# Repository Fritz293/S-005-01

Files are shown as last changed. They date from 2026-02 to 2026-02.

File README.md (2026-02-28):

# Raspberry Pi Multi-Status LED HAT

An industrial-grade Raspberry Pi HAT designed for high-visibility status monitoring using the **OSRAM DISPLIX® P3333 RGB LED** array. This board features professional-level power protection and follows the official Raspberry Pi HAT specifications.

## 🚀 Current Progress: Phase 1 (Schematic Complete)
- [x] Power Filtering & ESD Protection
- [x] High-Efficiency Reverse Polarity Protection (P-MOSFET)
- [x] Logic Level Shifting for 5V LED Driving
- [x] HAT ID EEPROM Implementation
- [ ] PCB Layout & Routing (Next Step)

---

## 🛠 Hardware Specifications

### 1. Power & Protection
To ensure the Raspberry Pi 5 remains stable during transient spikes, the 5V rail includes:
* **Reverse Polarity Protection:** Implemented via an **AO3401A P-Channel MOSFET**. This provides protection with negligible voltage drop (<0.05V) compared to a standard Schottky diode.
* **Overvoltage Protection:** Dual **5.6V 3W Zener/TVS diodes** ($D10, D11$).
* **Current Limiting:** A **375mA Fuse (F1)** protects the logic from downstream shorts.
* **Filtering:** 10µF and 100nF ceramic/tantalum capacitors for noise decoupling.

### 2. LED Driver Circuit
The board drives an **OSRAM KRTB LSLPS1.32** RGB LED via a high-side/low-side configuration:
* **Switching:** Three **BSS138 N-MOSFETs** act as logic-level shifters, allowing the Pi's 3.3V GPIOs to safely switch the 5V LED rail.
* **Current Calibration (at 20mA):**
    * **Red:** 150Ω
    * **Green:** 120Ω (Updated for Osram Vf)
    * **Blue:** 110Ω (Updated for Osram Vf)
* **ESD Safety:** **PESD5V0S1UL** protection diodes are placed at the external connector and MOSFET drains to prevent static damage.

### 3. Controller Interface
| Function | GPIO | Physical Pin |
| :--- | :--- | :--- |
| **Power/Idle** | GPIO 17 | Pin 11 |
| **Media Activity** | GPIO 27 | Pin 13 |
| **Error State** | GPIO 22 | Pin 15 |
| **ID_SDA** | EEPROM Data | Pin 27 |
| **ID_SCL** | EEPROM Clock | Pin 28 |

---

## 📝 Design Notes
> **Note on EEPROM Wiring:** The AT24C32 EEPROM is connected to the dedicated `ID_SD` and `ID_SC` pins (Pins 27/28) to allow the Raspberry Pi to automatically load the device tree overlay at boot.

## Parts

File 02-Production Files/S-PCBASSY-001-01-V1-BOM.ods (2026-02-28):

 | Component list
 |  |  |  | BOM for Variant [V1] of Project [S-PCBASSY-001-01.PrjPCB] (PCB Document : S-PCBASSY-001-01.PcbDoc)
 | Project: |  |  | S-PCBASSY-001-01-V1-BOM
 | Variant: |  |  | V1
 | Report Date:
 | Print Date: |  |  |  |  |  |  |  |  |  |  | Alternative Supplier |  | Equivalent Part #
# | LibRef | Manufacturer | Part # | Supplier | Supplier Part # | Description | Footprint1 | Designator | Value | Temp Range | Production Supplier | Supplier 2 | Supplier 2 Part # | Equivalent Part # | Equivalent Manufacturer | Equivalent Supplier | Equivalent Supplier Part # | Quantity | DNP
1 | 100n |  |  |  |  |  | Capacitor_SMD:C_0603_1608Metric | C1 |  |  |  |  |  |  |  |  |  | 1 |  | ~
2 | KEMET T491A106K016AT | KEMET | T491A106K016AT | Mouser | 80-T491A106K016 | Tantalum Capacitors - Solid SMD 16V 10uF 1206 10% ESR=3Ohms | Capacitor_Tantalum_SMD:CP_EIA-3216-18_Kemet-A | C2 | 10uF |  |  |  |  |  |  |  |  | 1 |  | https://octopart.com/part/kemet/T491A106K016AT
3 | Samsung CL21B104KBCNNNC | Samsung Electro-Mechanics | CL21B104KBCNNNC | DigiKey | 1276-1003-1-ND | CAP CER 0.1UF 50V X7R 0805 | Capacitor_SMD:C_0805_2012Metric | C3 | 0.1uF |  |  |  |  |  |  |  |  | 1 |  | https://octopart.com/search?q=Samsung+CL21B104KBCNNNC&currency=USD&specs=0
4 | PESD5V0L1ULD | Nexperia | PESD5V0L1ULD,315 | Mouser | 771-PESD5V0L1ULD315 | ESD Protection Diodes / TVS Diodes PESD5V0L1ULD/SOD882D/XSON2 | Diode_SMD:D_SOD-882D | D1,D3, D2 |  |  |  |  |  |  |  |  |  | 2 | DNP | "https://assets.nexperia.com/documents/data-sheet/PESD5V0L1ULD.pdf
6 | PESD5V0S1UL | Nexperia | PESD5V0L1ULD,315 | Mouser | 771-PESD5V0L1ULD315 | ESD Protection Diodes / TVS Diodes PESD5V0L1ULD/SOD882D/XSON2 | Diode_SMD:D_SOD-882 | D4,D5,D6,D7,D8,D9 |  |  |  |  |  |  |  |  |  | 8 |  | https://assets.nexperia.com/documents/data-sheet/PESD5V0S1UL.pdf
7 | 5V6, 3W | Vishay | BZG05C5V6-E3-TR | RS | 699-7758 | Zener Diodes 1.25W, BZG05C Series, Vishay Semiconductor | Diode_SMD:D_SMA | D10,D11 |  |  |  |  |  |  |  |  |  | 2 |  | https://za.rs-online.com/web/p/zener-diodes/6997758
8 | LED | OSRAM | LG R971 | EBV Elektronik | LG R971 | Green 570nm LED Indication - Discrete 2.2V 0805 (2012 Metric) | LED_SMD:LED_0603_1608Metric | D12 |  |  |  |  |  |  |  |  |  | 1 |  | ~
9 | SS14 | Vishay | SS14-E3/61T | Mouser |  | Schottky Rectifier 40V 1A SMA (Do Not Populate | Diode_SMD:D_SMA | D13 |  |  |  |  |  |  |  |  |  | 1 | DNP | https://www.vishay.com/docs/88746/ss12.pdf
10 | 375mA | Littelfuse | 0467.375NR | Mouse r |  | Fuse 375mA 32V 0603 Fast Acting | Fuse:Fuse_0603_1608Metric | F1 |  |  |  |  |  |  |  |  |  | 1 |  | https://www.littelfuse.com/media?itemid=cefcd49a-0e08-48b9-a5f1-60cfdadaed6d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
11 | GPIO |  |  |  |  |  | Connector_PinSocket_2.54mm:PinSocket_2x20_P2.54mm_Vertical | J1 |  |  |  |  |  |  |  |  |  | 1 |  | ~
12 | 43650-0428 | Molex | 436500428 | Mouser |  | Connector Header Micro-Fit 3.0 4 Pos | Connector:43650-04YY_272829 | J2 |  |  |  |  |  |  |  |  |  | 1 |  | https://www.molex.com/pdm_docs/sd/436500227_sd.pdf
13 | ID_WP |  |  |  |  |  | Connector_PinHeader_2.54mm:PinHeader_1x02_P2.54mm_Vertical_SMD_Pin1Left | JP1 |  |  |  |  |  |  |  |  |  | 1 |  | ~
14 | BSS138 | ONsemi | BSS138 | Mouser |  | N-Channel MOSFET 50V 360mA SOT-23 | Package_TO_SOT_SMD:SOT-23 | Q1,Q2,Q3 |  |  |  |  |  |  |  |  |  | 3 |  | https://www.onsemi.com/pub/Collateral/BSS138-D.PDF
15 | AO3401A | Alpha & Omega | AO3401A | Mouser |  | P-Channel MOSFET 30V 4A SOT-23 | Package_TO_SOT_SMD:SOT-23 | Q4 |  |  |  |  |  |  |  |  |  | 1 |  | http://www.aosmd.com/pdfs/datasheet/AO3401A.pdf
16 | 3.9k | Yageo | RC0603FR-073K9L |  |  | Thick Film Resistor, 1%, 0.1W (I2C Pull-ups) | Capacitor_SMD:C_0603_1608Metric | R1,R2 |  |  |  |  |  |  |  |  |  | 2 |  | ~
17 | 2k2 | Panasonic | ERJ-3EKF2201V |  |  | Thick Film Resistor, 1%, 0.1W (5V Power Indicator) | Resistor_SMD:R_0603_1608Metric_Pad0.98x0.95mm_HandSolder | R3 |  |  |  |  |  |  |  |  |  | 1 |  | ~
18 | 100k | Yageo | RC0603FR-07100KL |  |  | Thick Film Resistor, 1%, 0.1W (P-FET Gate Pull-down) | Resistor_SMD:R_0603_1608Metric_Pad0.98x0.95mm_HandSolder | R4 |  |  |  |  |  |  |  |  |  | 1 |  | ~
19 | 100 | Vishay | CRCW0603100RFKEA |  |  | Thick Film Resistor, 1%, 0.1W (Gate Damping) | Capacitor_SMD:C_0603_1608Metric,Resistor_SMD:R_0603_1608Metric_Pad0.98x0.95mm_HandSolder | Rg1,Rg2,Rg3,Rg6 |  |  |  |  |  |  |  |  |  | 4 |  | ~
20 | 150 | Panasonic | ERJ-3EKF1500V |  |  | Thick Film Resistor, 1%, 0.1W (Red/Error LED Limiter) | Capacitor_SMD:C_0603_1608Metric | Rg4,Rg5 |  |  |  |  |  |  |  |  |  | 2 |  | ~
21 | 10k | Yageo | RC0603FR-0710KL |  |  | Thick Film Resistor, 1%, 0.1W (Logic Pull-downs) | Capacitor_SMD:C_0603_1608Metric | Rpd1,Rpd2,Rpd3 |  |  |  |  |  |  |  |  |  | 3 |  | ~
22 | CAT24C256 | ONsemi | CAT24C256WI-GT3 | Mouser |  | EEPROM 256kb I2C 1MHz SOIC-8 | Package_SO:SOIC-8_3.9x4.9mm_P1.27mm | U1 |  |  |  |  |  |  |  |  |  | 1 |  | https://www.onsemi.cn/PowerSolutions/document/CAT24C256-D.PDF

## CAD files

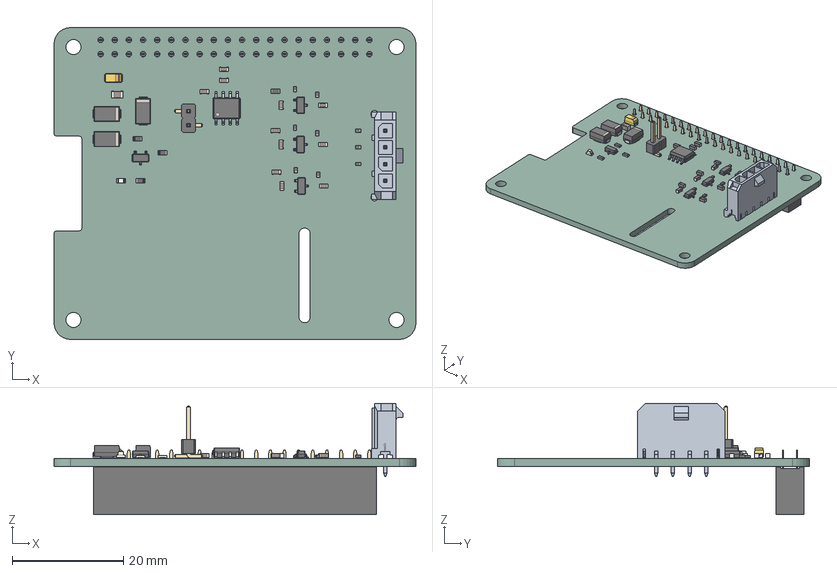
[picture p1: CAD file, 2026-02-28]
05-Production Documentation/06-Mechanical/S-PCBASSY-001-01.step
65.0 x 56.0 x 20.0 mm
C_0603_1608Metric x 11
D_SMA x 3
SOT-23 x 4
R_0603_1608Metric x 3
D_SOD-882D x 2
D_SOD-882 x 7
LED_0603_1608Metric
Fuse_0603_1608Metric
PinHeader_1x02_P2.54mm_Vertical_SMD_Pin1Left
C_0805_2012Metric
SOIC-8_3.9x4.9mm_P1.27mm
CP_EIA-3216-18_Kemet-A
PinSocket_2x20_P2.54mm_Vertical
S-PCBASSY-001-01_PCB

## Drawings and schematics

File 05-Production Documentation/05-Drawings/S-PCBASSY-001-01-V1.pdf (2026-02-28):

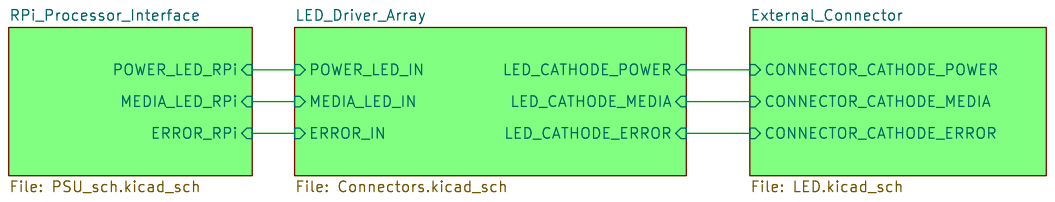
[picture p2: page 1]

Id: 1/4 Title: File: S-PCBASSY-001-01.kicad_sch Sheet: /

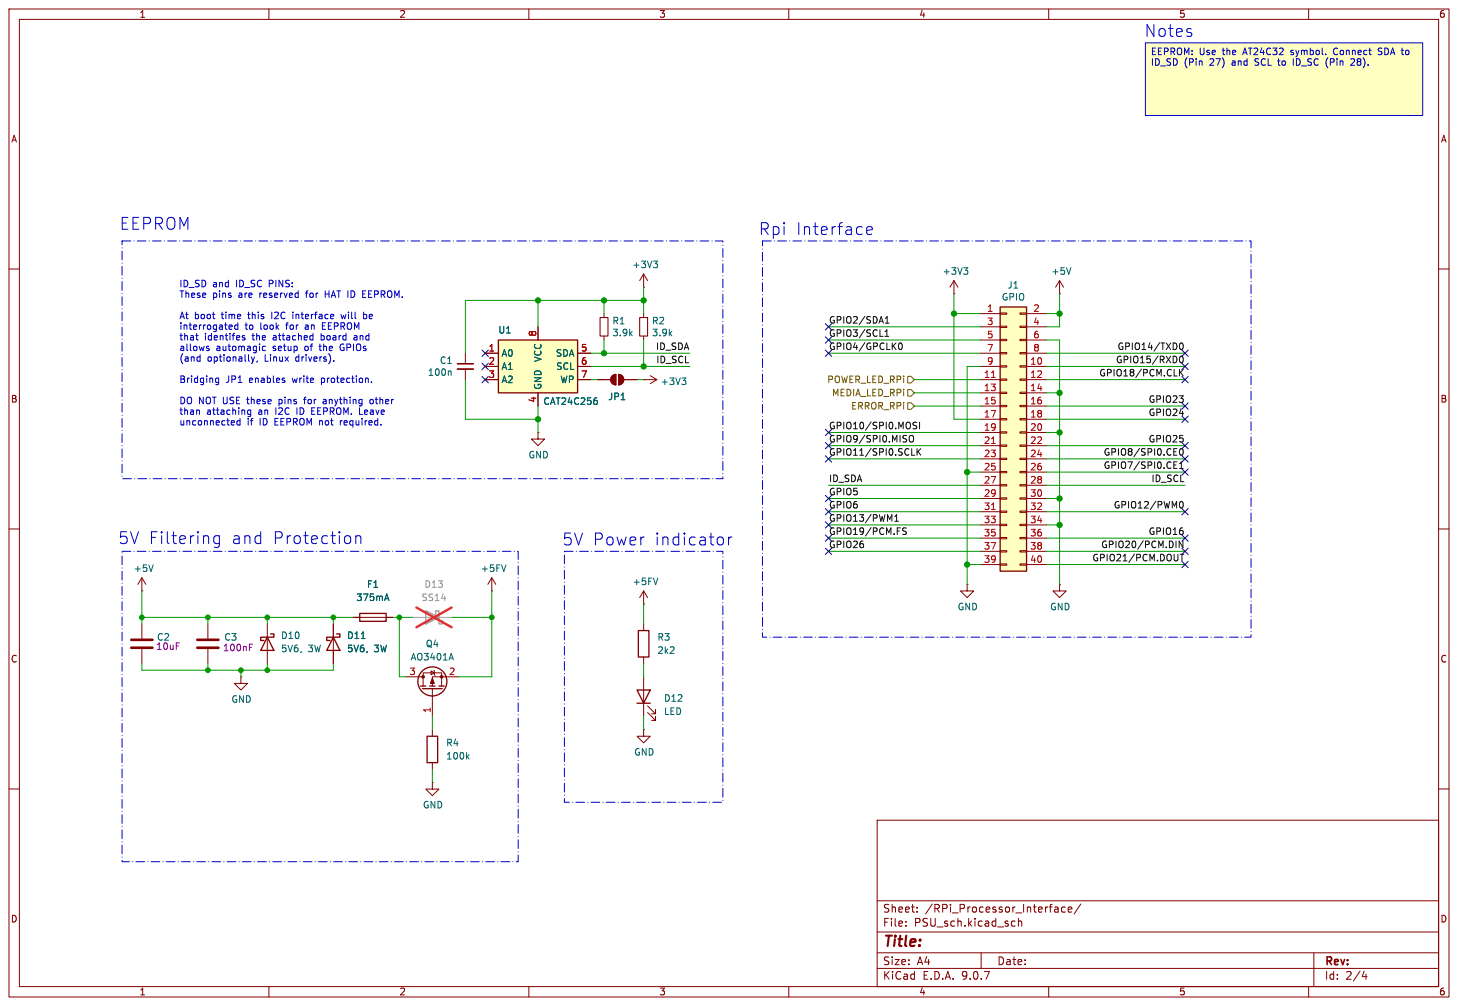
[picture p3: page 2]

ID_SD (Pin 27) and SCL to ID_SC (Pin 28).

Id: 2/4 Title: File: PSU_sch.kicad_sch Sheet: /RPi_Processor_Interface/

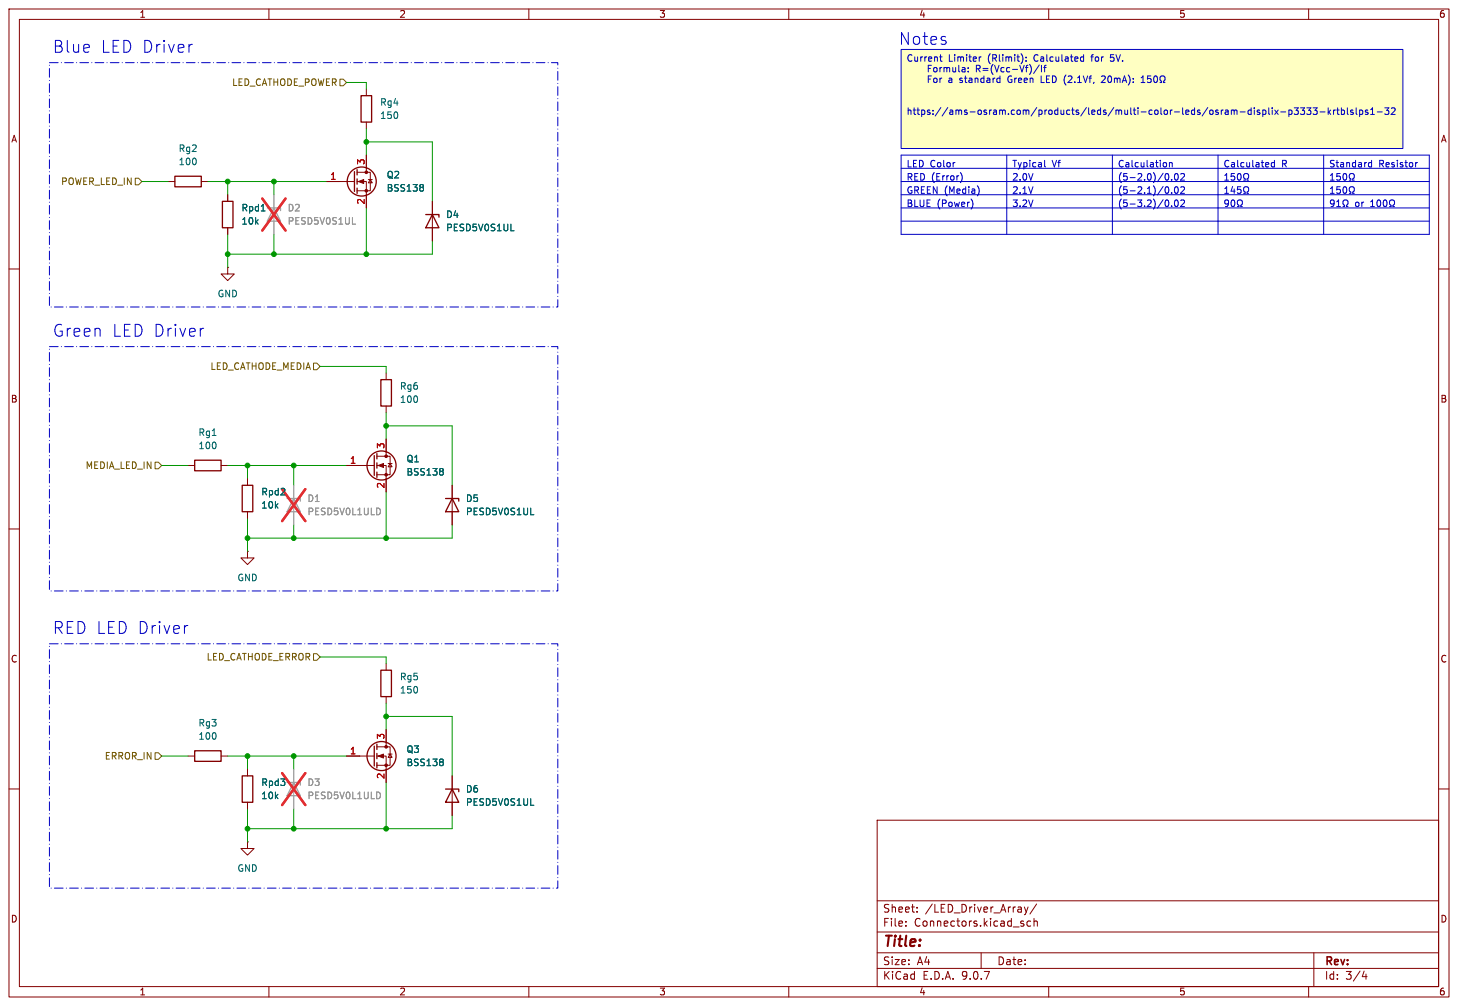
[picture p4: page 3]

https://ams-osram.com/products/leds/multi-color-leds/osram-displix-p3333-krtblslps1-32

LED Color | Typical þÿVf  2.0V 2.1V | Calculation þÿ(5"2.0)/0.02 þÿ(5"2.1)/0.02 | Calculated þÿ150© þÿ145© R | Standard Resistor RED (Error) þÿ150© GREEN (Media) þÿ150©

BLUE (Power) | 3.2V | þÿ(5"3.2)/0.02 | þÿ90© | þÿ91©or þÿ100©

Id: 3/4 Title: File: Connectors.kicad_sch Sheet: /LED_Driver_Array/

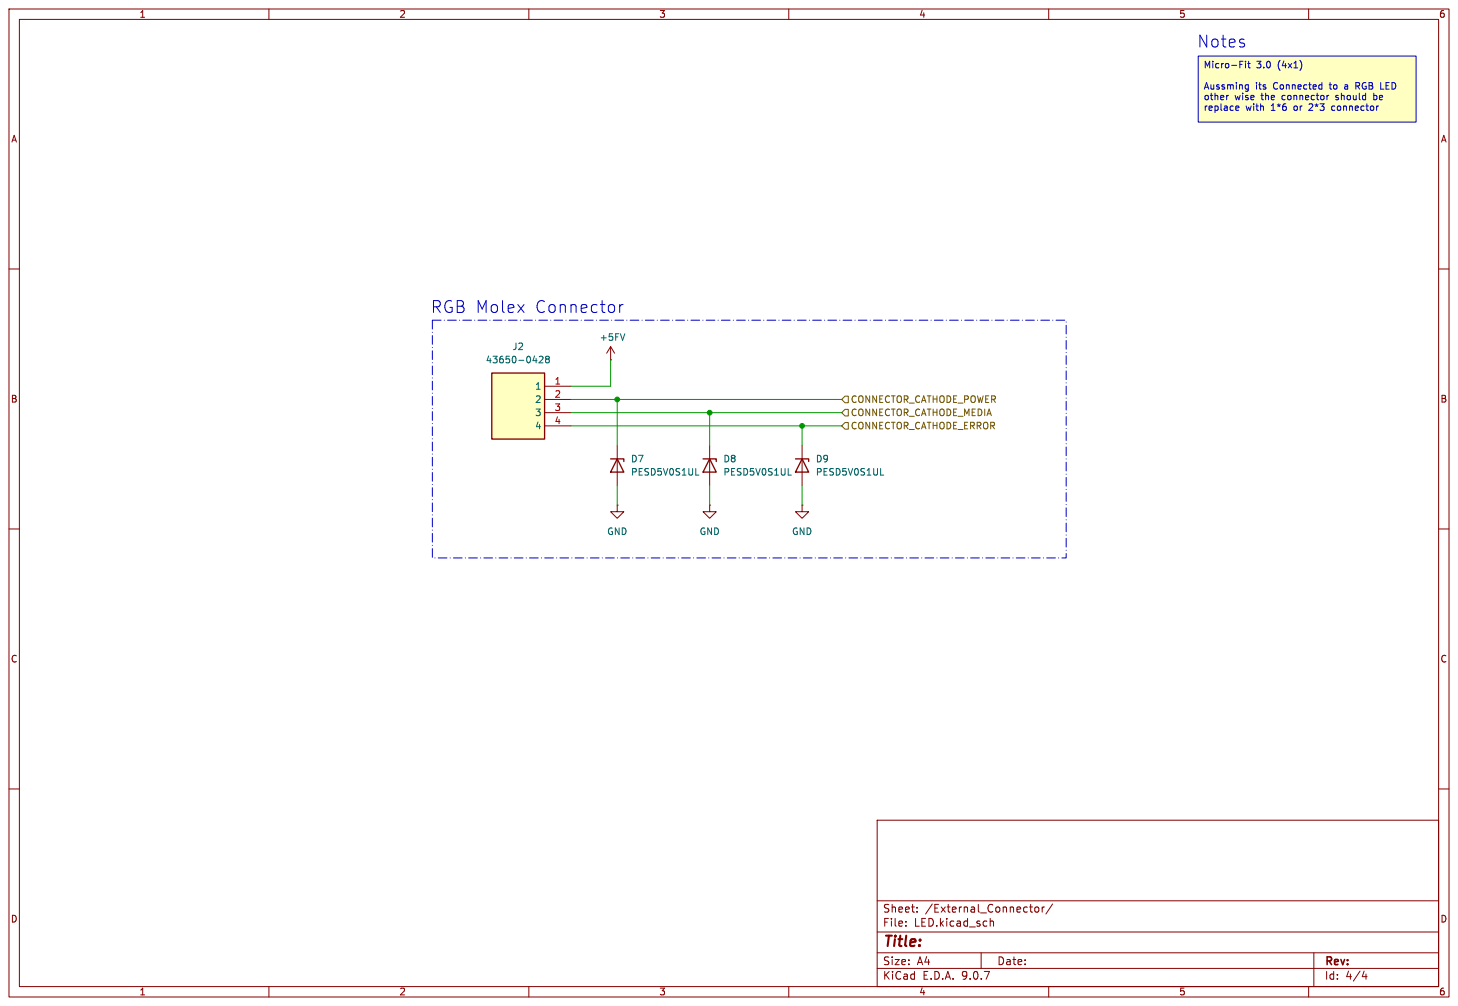
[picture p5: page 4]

Aussming its Connected to a RGB LED

replace with 1*6 or 2*3 connector RGB Molex Connector

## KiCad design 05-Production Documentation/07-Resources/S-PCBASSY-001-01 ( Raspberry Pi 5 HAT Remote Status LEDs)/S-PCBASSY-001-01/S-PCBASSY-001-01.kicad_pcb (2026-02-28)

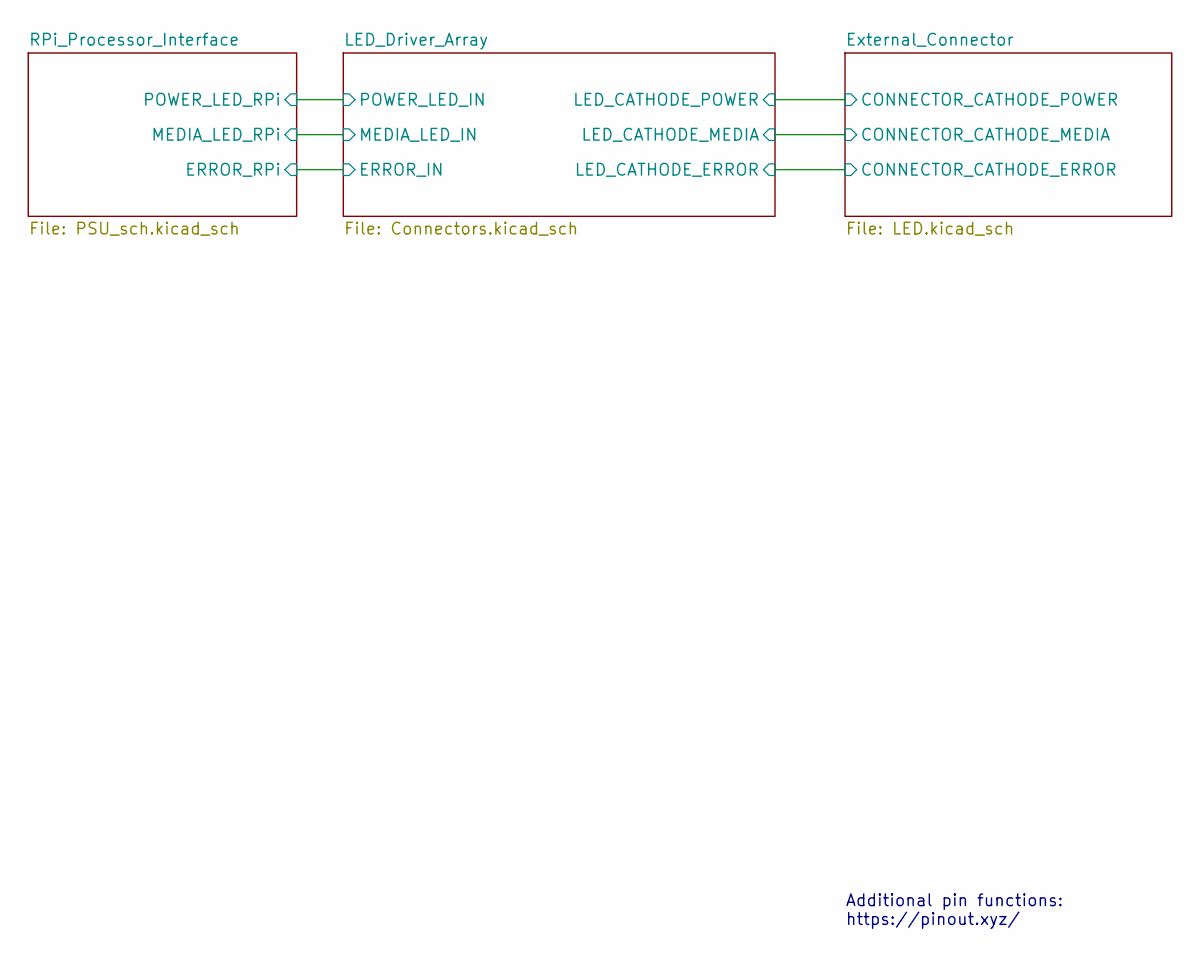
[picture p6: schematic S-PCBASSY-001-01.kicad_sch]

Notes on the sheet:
Additional pin functions: https://pinout.xyz/

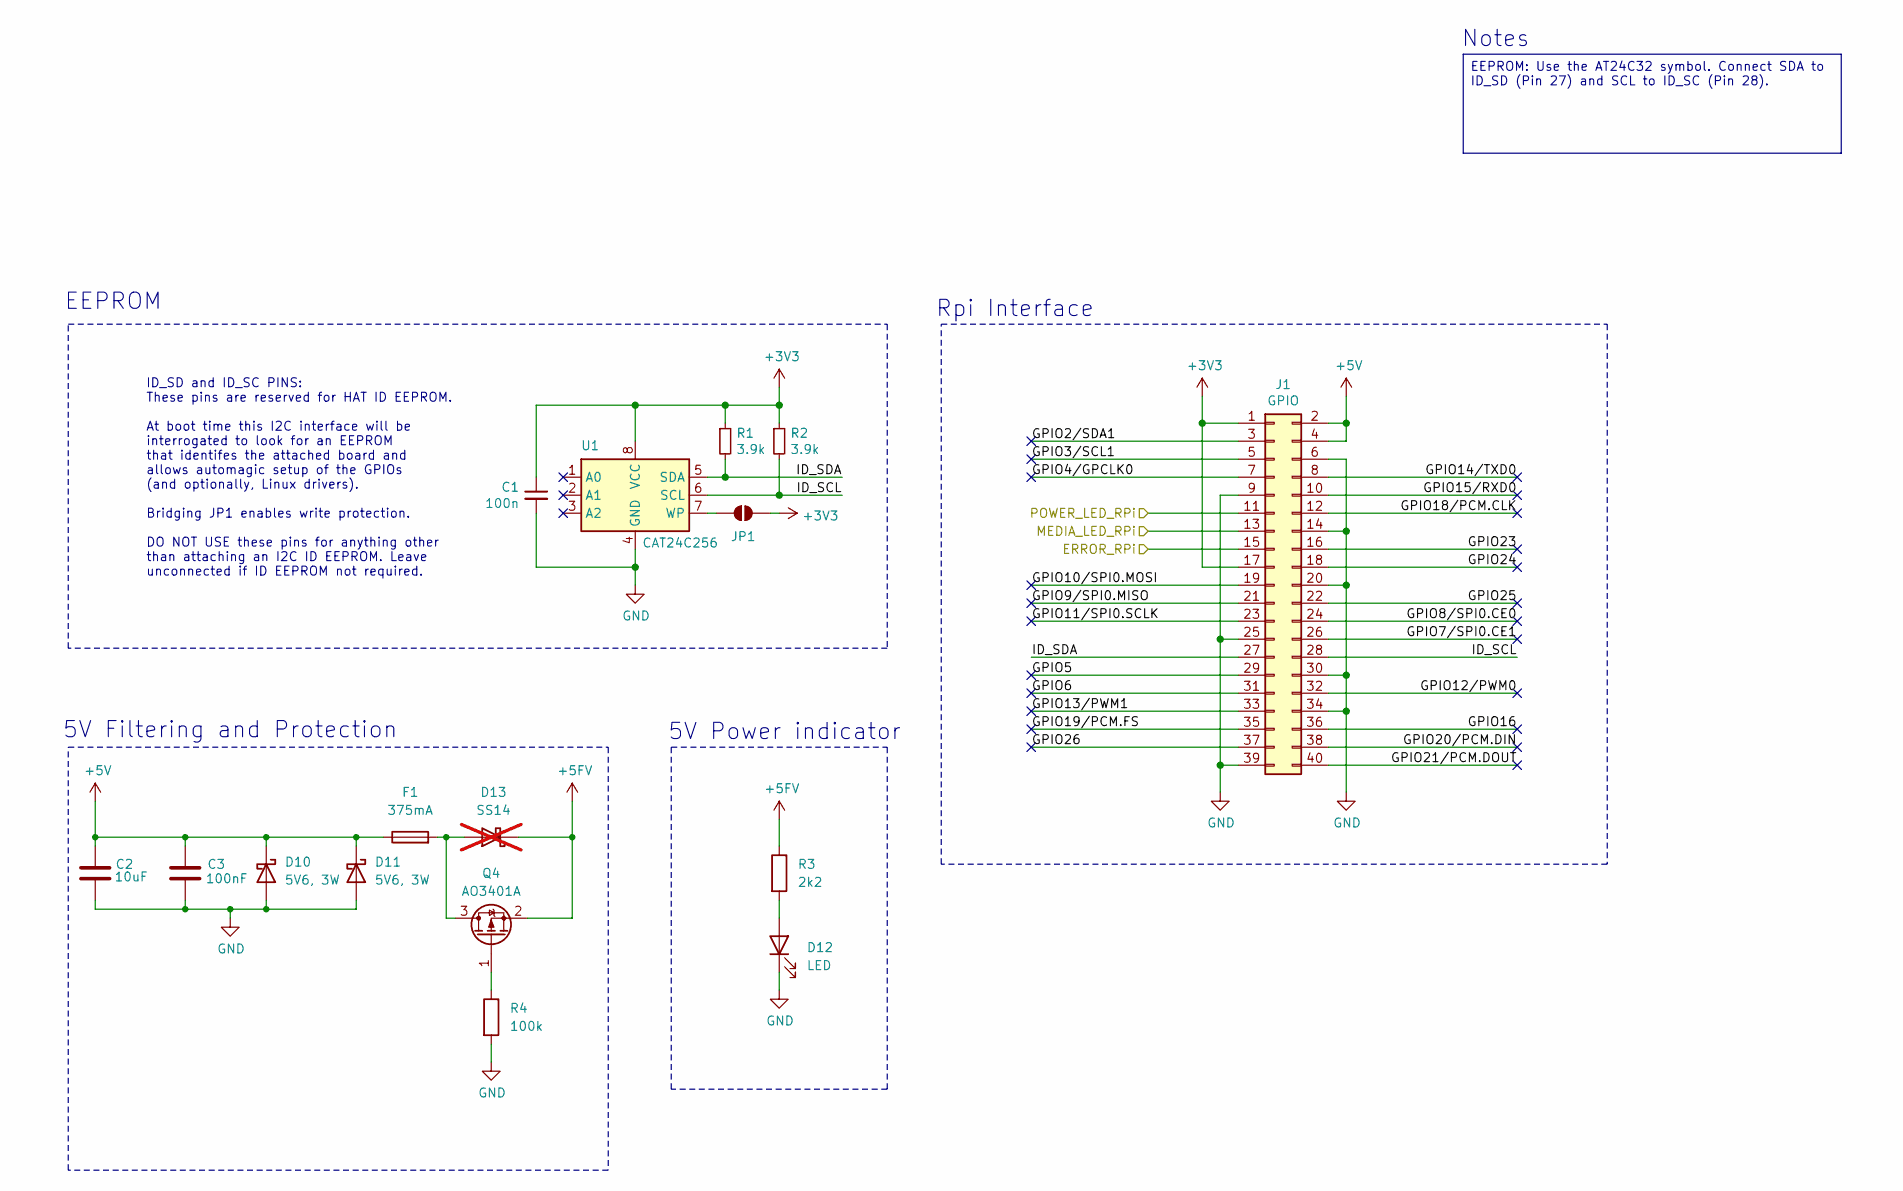
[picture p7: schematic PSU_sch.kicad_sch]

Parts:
C1: 100n; C_0603_1608Metric
C2: KEMET T491A106K016AT; CP_EIA-3216-18_Kemet-A
C3: Samsung CL21B104KBCNNNC; C_0805_2012Metric
D10, D11: 5V6, 3W; D_SMA
D12: LED; LED_0603_1608Metric
D13: SS14; D_SMA; not fitted
F1: 375mA; Fuse_0603_1608Metric
J1: GPIO; PinSocket_2x20_P2.54mm_Vertical
JP1: ID_WP; PinHeader_1x02_P2.54mm_Vertical_SMD_Pin1Left
Q4: AO3401A; SOT-23
R1, R2: 3.9k; C_0603_1608Metric
R3: 2k2; R_0603_1608Metric_Pad0.98x0.95mm_HandSolder
R4: 100k; R_0603_1608Metric_Pad0.98x0.95mm_HandSolder
U1: CAT24C256; SOIC-8_3.9x4.9mm_P1.27mm

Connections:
+3V3: C1.1, J1.1, J1.17, JP1.2 (B), R1.1, R2.1, U1.8 (VCC)
+5FV: D13.1 (K), Q4.2 (S), R3.1; also elsewhere on the board
+5V: C2.1, C3.1, D10.1 (K), D11.1 (K), F1.1, J1.2, J1.4
/LED_Driver_Array/ERROR_IN: J1.15; also elsewhere on the board
/LED_Driver_Array/MEDIA_LED_IN: J1.13; also elsewhere on the board
/LED_Driver_Array/POWER_LED_IN: J1.11; also elsewhere on the board
/RPi_Processor_Interface/GPIO2/SDA1: J1.3
/RPi_Processor_Interface/GPIO3/SCL1: J1.5
/RPi_Processor_Interface/GPIO4/GPCLK0: J1.7
/RPi_Processor_Interface/GPIO5: J1.29
/RPi_Processor_Interface/GPIO6: J1.31
/RPi_Processor_Interface/GPIO7/SPI0.CE1: J1.26
/RPi_Processor_Interface/GPIO8/SPI0.CE0: J1.24
/RPi_Processor_Interface/GPIO9/SPI0.MISO: J1.21
/RPi_Processor_Interface/GPIO10/SPI0.MOSI: J1.19
/RPi_Processor_Interface/GPIO11/SPI0.SCLK: J1.23
/RPi_Processor_Interface/GPIO12/PWM0: J1.32
/RPi_Processor_Interface/GPIO13/PWM1: J1.33
/RPi_Processor_Interface/GPIO14/TXD0: J1.8
/RPi_Processor_Interface/GPIO15/RXD0: J1.10
/RPi_Processor_Interface/GPIO16: J1.36
/RPi_Processor_Interface/GPIO18/PCM.CLK: J1.12
/RPi_Processor_Interface/GPIO19/PCM.FS: J1.35
/RPi_Processor_Interface/GPIO20/PCM.DIN: J1.38
/RPi_Processor_Interface/GPIO21/PCM.DOUT: J1.40
/RPi_Processor_Interface/GPIO23: J1.16
/RPi_Processor_Interface/GPIO24: J1.18
/RPi_Processor_Interface/GPIO25: J1.22
/RPi_Processor_Interface/GPIO26: J1.37
/RPi_Processor_Interface/ID_SCL: J1.28, R2.2, U1.6 (SCL)
/RPi_Processor_Interface/ID_SDA: J1.27, R1.2, U1.5 (SDA)
GND: C1.2, C2.2, C3.2, D10.2 (A), D11.2 (A), D12.1 (K), J1.6, J1.9, J1.14, J1.20, J1.25, J1.30, J1.34, J1.39, R4.2, U1.4 (GND); also elsewhere on the board
unnamed: D12.2 (A), R3.2
unnamed: D13.2 (A), F1.2, Q4.3 (D)
unnamed: JP1.1 (A), U1.7 (WP)
unnamed: Q4.1 (G), R4.1

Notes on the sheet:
5V Filtering and Protection
5V Power indicator
EEPROM
Rpi Interface
ID_SD and ID_SC PINS: These pins are reserved for HAT ID EEPROM. At boot time this I2C interface will be interrogated to look for an EEPROM that identifes the attached board and allows automagic setup of the GPIOs (and optionally, Linux drivers). Bridging JP1 enables write protection. DO NOT USE th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
Notes
EEPROM: Use the AT24C32 symbol. Connect SDA to ID_SD (Pin 27) and SCL to ID_SC (Pin 28).

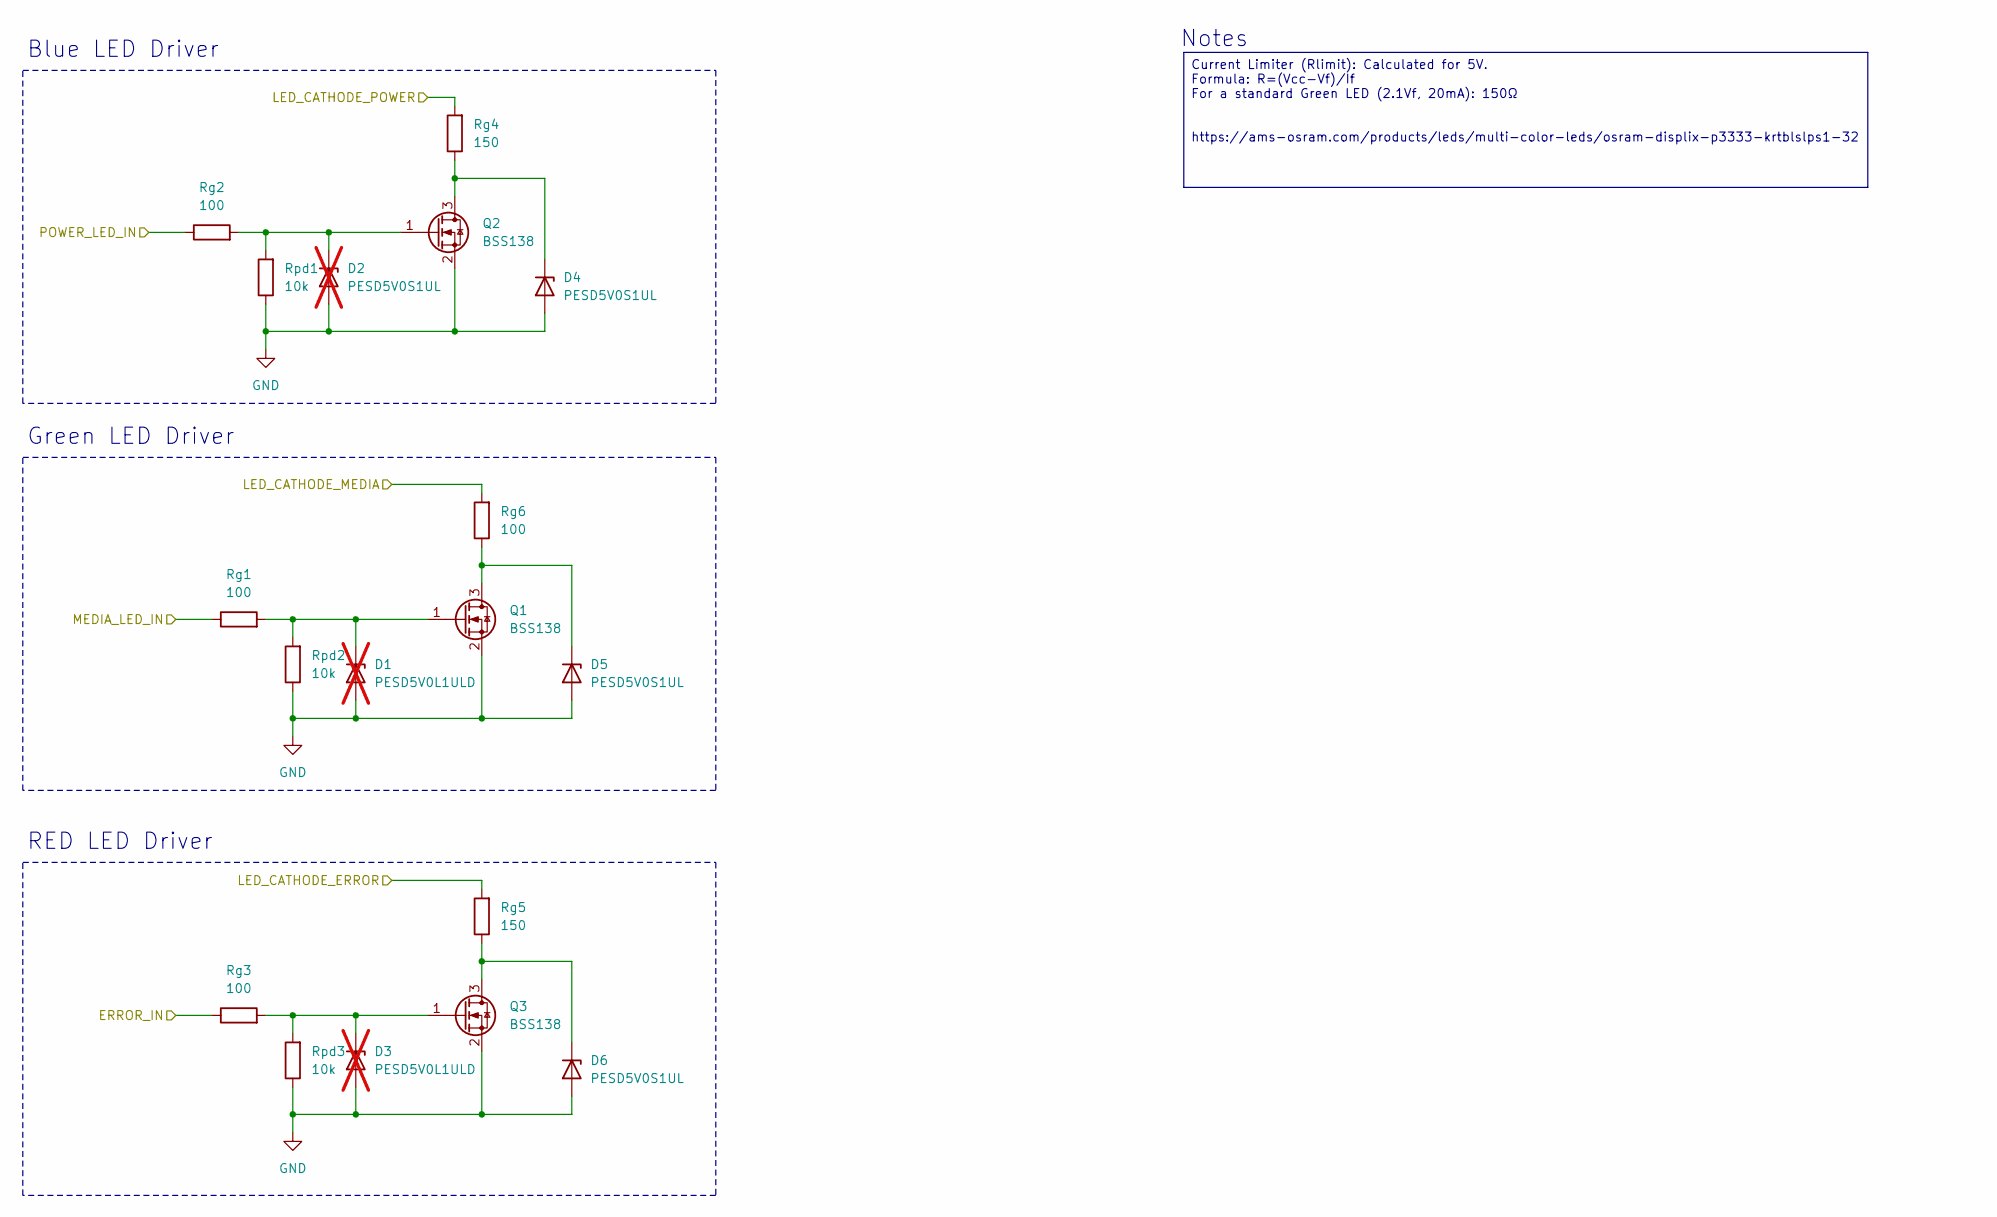
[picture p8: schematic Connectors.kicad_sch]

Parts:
D1, D3: PESD5V0L1ULD; D_SOD-882D; not fitted
D2: PESD5V0S1UL; D_SOD-882; not fitted
D4, D5, D6: PESD5V0S1UL; D_SOD-882
Q1, Q2, Q3: BSS138; SOT-23
Rg1, Rg2, Rg6: 100; C_0603_1608Metric
Rg3: 100; R_0603_1608Metric_Pad0.98x0.95mm_HandSolder
Rg4, Rg5: 150; C_0603_1608Metric
Rpd1, Rpd2, Rpd3: 10k; C_0603_1608Metric

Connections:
/External_Connector/CONNECTOR_CATHODE_ERROR: Rg5.2; also elsewhere on the board
/External_Connector/CONNECTOR_CATHODE_MEDIA: Rg6.2; also elsewhere on the board
/External_Connector/CONNECTOR_CATHODE_POWER: Rg4.2; also elsewhere on the board
/LED_Driver_Array/ERROR_IN: Rg3.1; also elsewhere on the board
/LED_Driver_Array/MEDIA_LED_IN: Rg1.1; also elsewhere on the board
/LED_Driver_Array/POWER_LED_IN: Rg2.1; also elsewhere on the board
GND: D1.2 (A), D2.2 (A), D3.2 (A), D4.2 (A), D5.2 (A), D6.2 (A), Q1.2 (S), Q2.2 (S), Q3.2 (S), Rpd1.1, Rpd2.1, Rpd3.1; also elsewhere on the board
unnamed: D1.1 (K), Q1.1 (G), Rg1.2, Rpd2.2
unnamed: D2.1 (K), Q2.1 (G), Rg2.2, Rpd1.2
unnamed: D3.1 (K), Q3.1 (G), Rg3.2, Rpd3.2
unnamed: D4.1 (K), Q2.3 (D), Rg4.1
unnamed: D5.1 (K), Q1.3 (D), Rg6.1
unnamed: D6.1 (K), Q3.3 (D), Rg5.1

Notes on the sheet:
Notes
RED LED Driver
Green LED Driver
Blue LED Driver
Current Limiter (Rlimit ): Calculated for 5V. Formula: R=(Vcc −Vf )/If  For a standard Green LED (2.1Vf , 20mA): 150Ω https://ams-osram.com/products/leds/multi-color-leds/osram-displix-p3333-krtblslps1-32

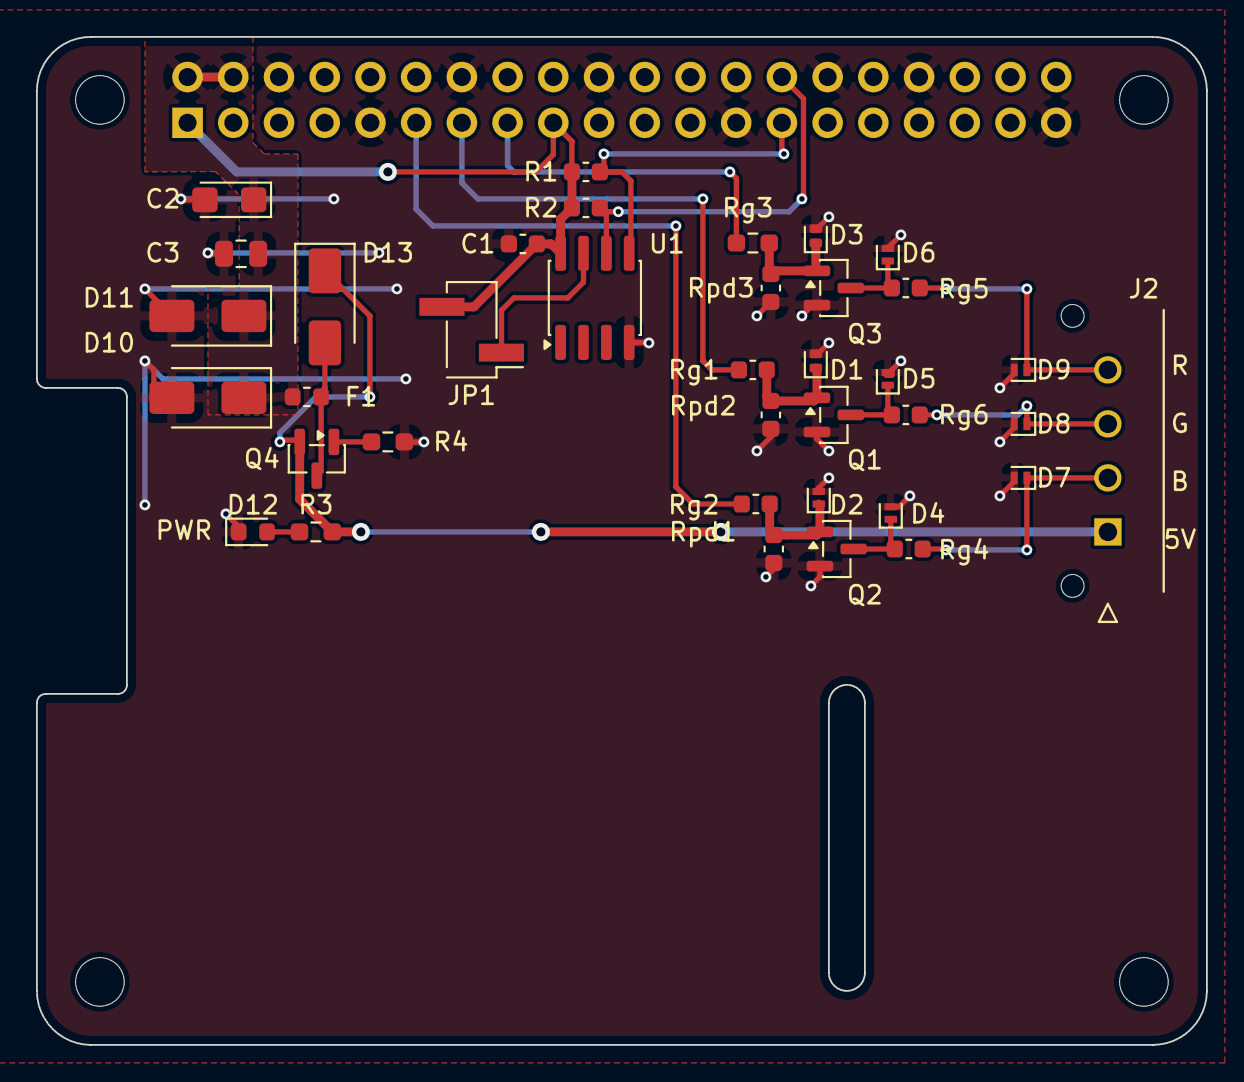
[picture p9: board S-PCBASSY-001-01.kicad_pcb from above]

Board: 2 copper layers, 65.0 x 56.0 mm, 42 parts (1 on the bottom side), 22 nets.

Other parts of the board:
D7, D8, D9: PESD5V0S1UL; D_SOD-882
J2: 43650-0428; 43650-04YY_272829
MH1, MH2, MH3, MH4: MountingHole_2.7mm_M2.5

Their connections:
+5FV: J2.1; also elsewhere on the board
/External_Connector/CONNECTOR_CATHODE_ERROR: D9.1 (K), J2.4; also elsewhere on the board
/External_Connector/CONNECTOR_CATHODE_MEDIA: D8.1 (K), J2.3; also elsewhere on the board
/External_Connector/CONNECTOR_CATHODE_POWER: D7.1 (K), J2.2; also elsewhere on the board
GND: D7.2 (A), D8.2 (A), D9.2 (A); also elsewhere on the board

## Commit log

2026-02-25 Init Folder Structure
    [S-PCBASSY-001-01.kicad_pcb, S-PCBASSY-001-01.kicad_sch]
2026-02-25 Board Outline done
    [S-PCBASSY-001-01-Edge_Cuts.dxf, S-PCBASSY-001-01.kicad_pcb]
2026-02-25 Updated Board Outline
    [S-PCBASSY-001-01-Edge_Cuts.dxf, S-PCBASSY-001-01.kicad_pcb, S-PCBASSY-001-01.kicad_sch]
2026-02-25 Added LED Mosfet Drivers
    [Connectors.kicad_sch, LED.kicad_sch, PSU_sch.kicad_sch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]
2026-02-25 WIP - LED Driver and Started with Connectors
    [Connectors.kicad_sch, LED.kicad_sch, PSU_sch.kicad_sch]
2026-02-28 Connector added with TVS still need to add polarity Protection
    [LED.kicad_sch, PSU_sch.kicad_sch, S-PCBASSY-001-01.kicad_sch]
2026-02-28 Added Decolping caps
    [PSU_sch.kicad_sch]
2026-02-28 Rpi Filetring and protection added
    [Connectors.kicad_sch, PSU_sch.kicad_sch]
2026-02-28 Schematics done
    [Connectors.kicad_sch, LED.kicad_sch, PSU_sch.kicad_sch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]
2026-02-28 ERC Completed and passed
    [LED.kicad_sch, PSU_sch.kicad_sch, S-PCBASSY-001-01.kicad_sch]
2026-02-28 Imported Components to PCB
    [Connectors.kicad_sch, PSU_sch.kicad_sch, S-PCBASSY-001-01.kicad_pcb]
2026-02-28 Layout done
    [PSU_sch.kicad_sch, S-PCBASSY-001-01.kicad_pcb]
2026-02-28 PCB Routing done
    [LED.kicad_sch, PSU_sch.kicad_sch, S-PCBASSY-001-01.kicad_pcb]
2026-02-28 Forgot the Gerbers
    [S-PCBASSY-001-01-B_Courtyard.gbr, S-PCBASSY-001-01-B_Cu.gbl, S-PCBASSY-001-01-B_Fab.gbr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]
